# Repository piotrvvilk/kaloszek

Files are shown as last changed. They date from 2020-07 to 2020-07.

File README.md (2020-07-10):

<H1>KALOSZEK - AccuWeather EPD frame</H1> 

<H2> General information</H2>
KALOSZEK is a simple device based on ESP8266 which gets informations shared by AccuWeather and present it on Eink Display. Kaloszek connects to AccuWeather server every 30min. Because AccuWeather trial version allows up to 50 calls per day, device uses 4 separate keys to make sure that the weather will be downloaded 24h a day. After downloading complete information about forcast and current weather, device displays it on screen and go to sleep.
<H2>
</H2>

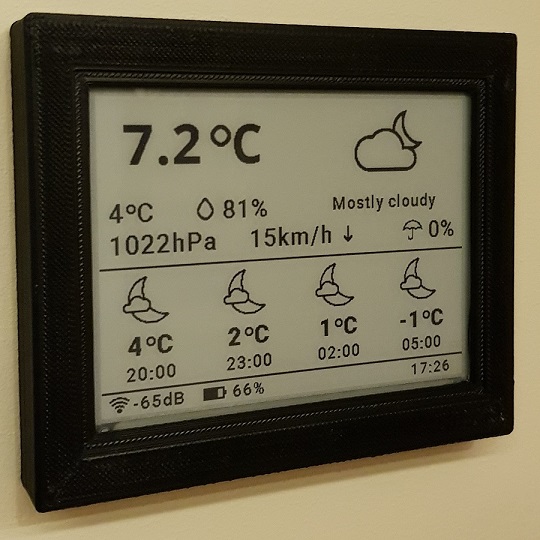
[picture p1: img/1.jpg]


<H2> Hardware </H2>

- Waveshare EPD  4.2inch, 400x300,

- NodeMCU v3,

- Li-ion battery (900mAh),

- Li-ion charger ST4054,

- Li-ion monitor MAX17048,

<H2> Connections </H2>

<H3> </H3>

<H4>EPD : </H4>

- D2 – BUSY

- D3 – CS

- D4 – RST

- D5 – CLK

- D7 – DIN

- D8 – DC (plus external pullup 3k3)

<H3> </H3>

<H4>  MAX17048:</H4>

- D1 – SDA

- D6 – SCL

<H3> </H3>

<H4>Wake up:</H4>

<H3> </H3>

- D0 – RST (remove while programming)

<H2> Libraries</H2>
<H3> </H3>
<H4>  WiFi</H4>
http://www.arduino.cc/en/Reference/WiFi
<H4>  EPD display</H4>
http://github.com/ZinggJM/GxEPD2
<H4>  AccuWeather</H4>
http://github.com/jackmax/AccuWeatherLibrary
<H4>  Json parser</H4>
http://github.com/squix78/json-streaming-parser
<H4>  MAX17048</H4>
http://github.com/hideakitai/MAX17048

<H2> Fonts generator</H2>
http://oleddisplay.squix.ch/#/home

<H2> Icons source</H2>
http://developer.accuweather.com/

<H2> Housing</H2>
<H5>Simple, black :). Designed and printed by Marcin:</H5>
http://www.instagram.com/creatorepic/

<H2> Settings</H2>

You have to edit „authentication.h” file and set your own WiFi SSID, password and accuweather keys. 

<H2> 
</H2>

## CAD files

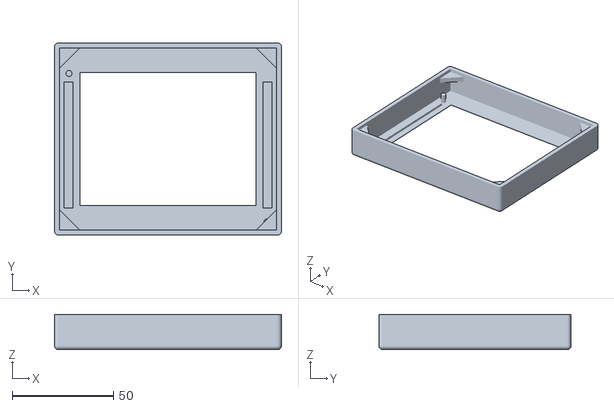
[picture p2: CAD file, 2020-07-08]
housing/kaloszek_housing.stl
112.3 x 95.1 x 17.5

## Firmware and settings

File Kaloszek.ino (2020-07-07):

//*********************************************************
//*****   PROJECT NAME: KALOSZEK                      *****
//*****                                               *****
//*****   VER: 2.6                                    *****
//*****                                               *****
//*****   DATE: 2020-07-07                            *****
//*****                                               *****
//*****                                               *****
//*********************************************************

//*********************************************************
//    LIBRARIES:
//    
//    EPD: https://github.com/ZinggJM/GxEPD2
//    ACCUWEATHER: https://github.com/jackmax/AccuWeatherLibrary
//    JSON ACCU: https://github.com/squix78/json-streaming-parser
//    MAX17048: https://github.com/hideakitai/MAX17048
//
//
//*********************************************************

//*********************************************************
#define ESP8266                     1

#include <ESP8266WiFi.h>
#include <WiFiClient.h>
#include <GxEPD2_BW.h>
#include <JsonListener.h>

#include "AccuWeatherLibrary.h"
#include "authentication.h"
#include "MAX17048.h"

//===========================================================================================================================================
#define     USE_EPD                 1
#define     USE_WIFI                1

#define     USE_ACCUWEATHER         1
#define     USE_HOURLY_FORCAST      1

#define     USE_WIFI_ICO            1

#define     USE_UART                1
//#define     PRINT_WEATHER           1

#define     USE_MAX17048            1

#define     UPDATE_PERIOD           1800                    //seconds
#define     WIFI_ERR_PERIOD         300                     //seconds

//=========================================================================================================================================== 
#include "epd_winddir.h"
#include "epd_iconpack.h"
#include "epd_main_iconpack.h" 
#include "epd_info_iconpack.h"

#include "data/fonts/RobotoMedPlain17.h"
#include "data/fonts/RobotoMedPlain18.h"
#include "data/fonts/RobotoMedPlain25_mod.h"
#include "data/fonts/RobotoBlackPlain25_mod.h"
#include "data/fonts/FreeSansBold52_mod.h"

//===========================================================================================================================================
GxEPD2_BW<GxEPD2_420, GxEPD2_420::HEIGHT> display(GxEPD2_420(/*CS=D3 ss*/ 0 , /*DC=D8*/ 15, /*RST=D4*/ 2, /*BUSY=D2*/ 4));    

const char str_sleep[] = "I'm going to sleep for ";
const char str_seconds[] = "seconds";
const char str_accuweather_err[] = "AccuWeather error";
const char str_wifi_err[] = "Error :(";
const char str_db[] = "dB";
const char str_st1_c[] = "*C";
const char str_uvindex[] = "UV:";
const char str_hpa[] = "hPa";
const char str_percent[] = "% ";
const char str_kmh[] = "km/h";
const char str_bat_error[] = "Battery error";

AccuweatherHourlyData dataH[12];
AccuweatherCurrentData dataC;

int wifi_connection_status;
int weather_status;
int hourly_status;

MAX17048 pwr_mgmt;

const uint16_t pos_x_big_ico = 260;

const int ACU_MAX_KEYS = 4;
int acu_key = 0;

Accuweather aw(acu_keys[0], 274663, "en-en", true);

//===========================================================================================================================================
//===========================================================================================================================================
//===========================================================================================================================================
void setup()
{
//---------------------------------------------------------------------------- SERIAL
#ifdef USE_UART
  Serial.begin(115200);
  Serial.println();
  Serial.println("Setup");
#endif
  delay(100);
  
//---------------------------------------------------------------------------- EPD
#ifdef USE_EPD
  display.init(115200);
#endif

//---------------------------------------------------------------------------- WIFI
#ifdef USE_WIFI
  wifi_connection_status = wifi_connect();
  int timeStart = millis();
#endif

//---------------------------------------------------------------------------- BATTERY
#ifdef USE_MAX17048
  Wire.begin(D1,D6);                          //sda,scl
  pwr_mgmt.attatch(Wire);

  #ifdef USE_UART
    //Serial.print("VCELL ADC : ");
    //Serial.println(pwr_mgmt.adc());
    Serial.print("VCELL V   : ");
    Serial.println(pwr_mgmt.voltage());
    Serial.print("VCELL SOC : ");
    Serial.print(pwr_mgmt.percent());
    Serial.println(" \%");
    //Serial.print("VCELL SOC : ");
    //Serial.print(pwr_mgmt.accuratePercent());
    //Serial.println(" \%");
    Serial.println();
  #endif
 
#endif

//---------------------------------------------------------------------------- ACCUWEATHER
  if (wifi_connection_status == 0)
  {
    do {
      weather_status = get_weather();
      #ifdef USE_UART
        Serial.print("Accu status:");
        Serial.println(weather_status);
      #endif

      hourly_status = get_hourly_forcast();
      #ifdef USE_UART
        Serial.print("Hourly status:");
        Serial.println(hourly_status);
      #endif
      
      if ((weather_status == 0) && (hourly_status == 0)) break;

      acu_key++;
      if (acu_key >= ACU_MAX_KEYS) break;
      Serial.println("Change Accuweather api key");
      aw.changeApiKey(acu_keys[acu_key]);

    } while ((weather_status != 0) || (hourly_status != 0));
  }
  

//---------------------------------------------------------------------------- DISPLAY DATA
#ifdef USE_EPD
  display_weather(wifi_connection_status, weather_status, hourly_status);
#endif

//---------------------------------------------------------------------------- GO TO SLEEP
  if (wifi_connection_status == 0)
  {
    go_to_sleep(UPDATE_PERIOD);
  }
  else
  {
    go_to_sleep(WIFI_ERR_PERIOD);
  }
}
//===========================================================================================================================================
//===========================================================================================================================================
//===========================================================================================================================================
void loop()
{
}

//===========================================================================================================================================
//===========================================================================================================================================
//===========================================================================================================================================
int wifi_connect()
{
//---------------------------------------------------------------------------- WIFI 1
  int i = 50;

  #ifdef USE_UART
    Serial.print("Connecting to: ");
    Serial.println(ssid_1);
  #endif 

  WiFi.mode(WIFI_STA);
  WiFi.begin(ssid_1, password_1);

  do
  {
    if (WiFi.status() == WL_CONNECTED) break;
    delay(500);
    #ifdef USE_UART
      Serial.println("Connecting to WiFi..");
    #endif  
  } while (--i);

  if(i)
  {
    #ifdef USE_UART
      Serial.println("Connected to the WiFi network :)");
      Serial.print("IP address: ");
      Serial.println(WiFi.localIP()); 
    #endif
    return 0;
  }
//---------------------------------------------------------------------------- WIFI 2 (alternative)
    i = 50;
  
    #ifdef USE_UART
      Serial.print("Connecting to: ");
      Serial.println(ssid_2);
    #endif 
  
    WiFi.mode(WIFI_STA);
    WiFi.begin(ssid_2, password_2);
  
    do
    {
      if (WiFi.status() == WL_CONNECTED) break;
      delay(500);
      #ifdef USE_UART
        Serial.println("Connecting to WiFi..");
      #endif  
    } while (--i);
  
    if(i)
    {
      #ifdef USE_UART
        Serial.println("Connected to the WiFi network :)");
        Serial.print("IP address: ");
        Serial.println(WiFi.localIP()); 
      #endif
      return 0;
    }
    else
    {
      #ifdef USE_UART
        Serial.println("WiFi error");
      #endif
        
      return -1;
    }
}

//===========================================================================================================================================
int get_weather()
{
#ifdef USE_ACCUWEATHER
  int timeStart = millis();

  int ret = aw.getCurrent(&dataC);

  if (ret != 0)
  {
    #ifdef USE_UART
      Serial.print("ACCUWEATHER ERROR: ");
      Serial.println(ret);
     #endif

    return ret;
  }

  while (aw.continueDownload() > 0)
  {
  }

  #ifdef PRINT_WEATHER
    print_actual_weather();
  #endif

  timeStart = millis() - timeStart;

  #ifdef USE_UART
    Serial.printf("Downloaded and parsed in %d ms\n", timeStart);
    Serial.println(String(ESP.getFreeHeap()));
  #endif  
  
  return 0;
#else                                                                 //fake data - epd test
  dataC.WeatherText = "Mostly cloudy";
  dataC.WeatherIcon = 7;
  dataC.Temperature = -16.60;
  dataC.RealFeelTemperature = 16.60;
  dataC.RelativeHumidity = 77.00;
  dataC.WindDirection = 115;
  dataC.WindSpeed = 6.70;
  dataC.UVIndex = 1;
  dataC.Pressure = 1023.00;
  return 0;
#endif
}
//===========================================================================================================================================
int get_hourly_forcast()
{
#ifdef USE_HOURLY_FORCAST

  int timeStart = millis();

  int ret = aw.getHourly(&dataH[0], 12);

  if (ret != 0)
  {
    #ifdef USE_UART
      Serial.print("ACCUWEATHER ERROR: ");
      Serial.println(ret);
    #endif
    
    return ret;
  }

  while (aw.continueDownload() > 0)
  {
  }

  //print_dataH();

  timeStart = millis() - timeStart;

  Serial.printf("Downloaded and parsed forcast in %d ms\n", timeStart);
  Serial.println(String(ESP.getFreeHeap()));
#else
  dataH[2].Temperature = -1.20;
  dataH[5].Temperature = 4.40;
  dataH[8].Temperature = 4.90;
  dataH[11].Temperature = 27.90;

  dataH[2].DateTime = "2019-09-21T15:19:21+00:00";
  dataH[5].DateTime = "2019-09-21T18:19:21+00:00";
  dataH[8].DateTime = "2019-09-21T11:19:21+00:00";
  dataH[11].DateTime = "2019-09-22T00:19:21+00:00";

  dataH[1].RainProbability = 13;
#endif

  return 0;
}

//===========================================================================================================================================
void display_weather(int wifi_connection_status, int w_status , int h_status)
{
  char new_date[32];
  char new_data[8];
  float my_temp;

  int pos_y_1_line = 64;    // aktualna temperatura
  int pos_y_2_line = 118;   // temperatura odczuwalna + UV
  int pos_y_w_line = 114;   // opis pogody
  int pos_y_3_line = 148;   // ciśnienie + wilgotność itd
  int pos_y_4_line = 244;   // temp prognozy
  int pos_y_5_line = 268;   // czas prognozy
  int pos_y_6_line = 295;   // status

  int pos_x_wind;
  int pos_x_wind_ico;
  
  int pos_x_prob;
  int pos_x_prob_ico;
  
  display.fillScreen(GxEPD_WHITE);
  display.setRotation(0);
  display.setTextColor(GxEPD_BLACK);
  
//----------------------------------------------------------------------------- background
  display.fillRect(1, 160, 399, 2, GxEPD_BLACK);
  display.fillRect(1, 276, 399, 2, GxEPD_BLACK);
  
//----------------------------------------------------------------------------- 1. line
  if (w_status == 0)
  {
    display.setFont(&Open_Sans_Bold_52);

    my_temp = round(dataC.Temperature * 10) / 10.0;
    display.setCursor(25, pos_y_1_line);
    display.print(my_temp,1);
    display.print(str_st1_c);

//----------------------------------------------------------------------------- 2. line    

//----------------------------------------------------- real_temp
    display.setFont(&Roboto_Medium_25);                                                    
    display.setCursor(10, pos_y_2_line);
   
    int real_temp = (int)(round(dataC.RealFeelTemperature));
    display.print(real_temp);
    display.print(str_st1_c);

//----------------------------------------------------- humidity
    int humidity = int(round(dataC.RelativeHumidity));

    display.drawBitmap(90, pos_y_2_line - 25, hum_ico, 32, 32, GxEPD_BLACK);          //wypozycjonowac
    display.setCursor(122, pos_y_2_line);
    display.print(humidity);
    display.print(str_percent);

//----------------------------------------------------- uv
    //int uv_index = (int)(round(dataC.UVIndex));
    //display.print(str_uvindex);
    //display.print(uv_index);

//----------------------------------------------------------------------------- 3. line

//----------------------------------------------------- pressure     
    int pressure = int(round(dataC.Pressure));
    
    display.setCursor(10, pos_y_3_line);
    display.print(pressure);
    display.print(str_hpa);
    
//----------------------------------------------------- wind 
    int wind_speed = (int)(round(dataC.WindSpeed));   

    if(wind_speed<10)                                                               //ok
    {
      pos_x_wind = 160;
      pos_x_wind_ico = 235;
    }
      else if((wind_speed>9)&&(wind_speed<100))                                     //ok
    {
      pos_x_wind = 150;
      pos_x_wind_ico = 235;
    }
    else                                                                            //ok
    {
      pos_x_wind = 145;
      pos_x_wind_ico = 245;
    }
    
    display.setCursor(pos_x_wind, pos_y_3_line);
    display.print(wind_speed);
    display.print(str_kmh);

    display_wind_dir(dataC.WindDirection, pos_x_wind_ico, pos_y_3_line - 33);       //ok

//----------------------------------------------------- probability
    int prob = (dataH[1].RainProbability);   
  
    if(prob<10)                                                                     //ok
    {
      pos_x_prob_ico = 320;
      pos_x_prob = 357;
    }
      else if((prob>9)&&(prob<100))                                                 //ok
    {
      pos_x_prob_ico = 307;
      pos_x_prob = 345;
    }
    else                                                                            //ok
    {
      pos_x_prob_ico = 295;
      pos_x_prob = 332;
    }

    display.drawBitmap(pos_x_prob_ico, pos_y_3_line - 27, infoIco5, 35, 35, GxEPD_BLACK);     //ok
    display.setCursor(pos_x_prob, pos_y_3_line);
    display.print(prob);
    display.print('%');

//----------------------------------------------------------------------------- main icon and weather description
    display_main_weather_icon(dataC.WeatherIcon, pos_x_big_ico, 4);
    
    uint16_t pos_x_description = set_weather_description_offset(dataC.WeatherText);
    
    display.setFont(&Roboto_Medium_18);                                
    display.setCursor(pos_x_description, pos_y_w_line);
    display.print(dataC.WeatherText);                                                                           

//----------------------------------------------------------------------------- 5. line - update time
    dataC.LocalObservationDateTime.toCharArray(new_date, 20);
    memmove(new_date, new_date + 11, 8);
    memcpy(new_data, new_date, 5);
    new_data[5] = 0;
    display.setCursor(335, pos_y_6_line);
    display.setFont(&Roboto_Medium_17);    
    display.print(new_data);
  }
  else
//----------------------------------------------------------------------------- accuweather error
  {
    display.setFont(&Roboto_Medium_17);    
    display.setCursor(232, pos_y_6_line);
    display.print(str_accuweather_err);
  }
  
//----------------------------------------------------------------------------- wifi
  display.setFont(&Roboto_Medium_17);   
  display.setCursor(30, pos_y_6_line);

#ifdef USE_WIFI_ICO
  display.drawBitmap(6, 281, wifi_ico, 24, 16, GxEPD_BLACK); 
#endif

  if (wifi_connection_status == 0)
  {
     #ifndef USE_WIFI_ICO
      display.print(WiFi.SSID());
      display.print(' ');
    #endif  
    
    display.print(WiFi.RSSI());
    
    display.print(str_db);
  }
  else
  {
    display.print(str_wifi_err);
  }

//----------------------------------------------------------------------------- battery
  display_battery(pos_y_6_line); 

//----------------------------------------------------------------------------- weather forcast
  if (h_status == 0) 
  {
    display_forcast(2, pos_y_4_line, pos_y_5_line);         //3h
    display_forcast(5, pos_y_4_line, pos_y_5_line);         //6h
    display_forcast(8, pos_y_4_line, pos_y_5_line);         //9h
    display_forcast(11, pos_y_4_line, pos_y_5_line);        //12h
  }

  display.display();
  display.powerOff();
  display.hibernate();
  Serial.println("EPD is sleeping");
}

//===========================================================================================================================================
void display_forcast(int idx, int pos_y_temp, int pos_y_time)
{
  float my_temp = round(dataH[idx].Temperature * 10) / 10.0;
  char new_date[32];
  char new_data[8];
  int pos_x_ico;
  int pos_x_time;
  int pos_x_temp;

//-------------------------------------------------- temp & ico
  int my_t = (int)(round(my_temp));  

  switch(idx)
  {
    case 2: pos_x_ico = 22; pos_x_time = pos_x_ico + 2; pos_x_temp = set_forcast_temperature_position(pos_x_ico, my_t); break;
    case 5: pos_x_ico = 122; pos_x_time = pos_x_ico + 2; pos_x_temp = set_forcast_temperature_position(pos_x_ico, my_t);  break;        
    case 8: pos_x_ico = 222; pos_x_time = pos_x_ico + 2; pos_x_temp = set_forcast_temperature_position(pos_x_ico, my_t); break;        
    case 11: pos_x_ico = 322; pos_x_time = pos_x_ico + 2; pos_x_temp = set_forcast_temperature_position(pos_x_ico, my_t); break;
  }
  
  display_hourly_weather_icon(dataH[idx].WeatherIcon, pos_x_ico, pos_y_temp - 80);

  display.setFont(&Roboto_Black_25); 
  display.setCursor(pos_x_temp, pos_y_temp);
  display.print(my_t);
  display.print(str_st1_c);

//-------------------------------------------------- time
  dataH[idx].DateTime.toCharArray(new_date, 20);
  memmove(new_date, new_date + 11, 8);
  memcpy(new_data, new_date, 5);
  new_data[5] = 0;

  display.setFont(&Roboto_Medium_18);                                            
  display.setCursor(pos_x_time, pos_y_time);
  display.print(new_data);
}

//===========================================================================================================================================
uint16_t set_weather_description_offset(String str)
{
  int16_t tbx, tby; 
  uint16_t tbw, tbh;

  display.setFont(&Roboto_Medium_18);                                
  display.getTextBounds(str.c_str(), 0, 0, &tbx, &tby, &tbw, &tbh);

  uint16_t x_center = pos_x_big_ico + (90/2);               //srodek ikonki pogody 90 - uwzglednic wielkosc ikonki w obliczeniach
  uint16_t  pos_x_napisu = (x_center - (tbw / 2)) - tbx;
 
  return pos_x_napisu;
}

//===========================================================================================================================================
int set_forcast_temperature_position(int pos_x, int temp)
{
  if(temp<-9)                               
  {
    return pos_x-8;
  }
  else if((temp>-10)&&(temp<0))             
  {
    return pos_x-2;
  }
  else if((temp>-1)&&(temp<10))            
  {
     return pos_x+4;
  }
  else                                    
  {
    return pos_x-2;
  }
}

//===========================================================================================================================================
void set_icon_offset(uint8_t w_number, int *x_pos, int *y_pos) {
#ifdef ICON_PACK_3
  switch (w_number)
  {
    case 3: {
        *y_pos += 2;
      } break;
    case 38: {
        *y_pos += 8;
      } break;
  }
#endif
}
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

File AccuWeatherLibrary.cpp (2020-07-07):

#include "AccuWeatherLibrary.h"
#include "JsonListener.h"

#define SIZE_OF_CONST_TABLE(x) sizeof(x)/sizeof(x[0])
#define STACK_HAS_SUFFIX(x) stackSuffix(x, SIZE_OF_CONST_TABLE(x))
/*
 *  Parser constants
 */
//A map to transform strings into tokens
static const std::map<const String, const AccuParserTokens> stringToTokenMap = {
    { "CloudCover", ACCUPARSERCloudCover },
    { "DailyForecasts", ACCUPARSERDailyForecasts },
    { "Date", ACCUPARSERDate },
    { "DateTime", ACCUPARSERDateTime },
    { "Day", ACCUPARSERDay },
    { "Degrees", ACCUPARSERDegrees },
    { "Direction", ACCUPARSERDirection },
    { "English", ACCUPARSEREnglish },
    { "EpochDate", ACCUPARSEREpochDate },
    { "EpochDateTime", ACCUPARSEREpochDateTime },
    { "EpochRise", ACCUPARSEREpochRise },
    { "EpochSet", ACCUPARSEREpochSet },
    { "EpochTime", ACCUPARSEREpochTime },
    { "HoursOfSun", ACCUPARSERHoursOfSun },
    { "Ice", ACCUPARSERIce },
    { "IceProbability", ACCUPARSERIceProbability },
    { "Icon", ACCUPARSERIcon },
    { "IconPhrase", ACCUPARSERIconPhrase },
    { "Imperial", ACCUPARSERImperial },
    { "IsDaylight", ACCUPARSERIsDaylight },
    { "IsDayTime", ACCUPARSERIsDayTime },
    { "LocalObservationDateTime", ACCUPARSERLocalObservationDateTime },
    { "LongPhrase", ACCUPARSERLongPhrase },
    { "Maximum", ACCUPARSERMaximum },
    { "Metric", ACCUPARSERMetric },
    { "Minimum", ACCUPARSERMinimum },
    { "Moon", ACCUPARSERMoon },
    { "Night", ACCUPARSERNight },
    { "Precip1hr", ACCUPARSERPrecip1hr },
    { "PrecipitationProbability", ACCUPARSERPrecipitationProbability },
    { "Pressure", ACCUPARSERPressure },
    { "Rain", ACCUPARSERRain },
    { "RainProbability", ACCUPARSERRainProbability },
    { "RealFeelTemperature", ACCUPARSERRealFeelTemperature },
    { "RealFeelTemperatureShade", ACCUPARSERRealFeelTemperatureShade },
    { "RelativeHumidity", ACCUPARSERRelativeHumidity },
    { "ShortPhrase", ACCUPARSERShortPhrase },
    { "Snow", ACCUPARSERSnow },
    { "SnowProbability", ACCUPARSERSnowProbability },
    { "Speed", ACCUPARSERSpeed },
    { "Sun", ACCUPARSERSun },
    { "Temperature", ACCUPARSERTemperature },
    { "ThunderstormProbability", ACCUPARSERThunderstormProbability },
    { "TotalLiquid", ACCUPARSERTotalLiquid },
    { "Unit", ACCUPARSERUnit },
    { "UVIndex", ACCUPARSERUVIndex },
    { "UVIndexText", ACCUPARSERUVIndexText },
    { "Value", ACCUPARSERValue },
    { "Visibility", ACCUPARSERVisibility },
    { "WeatherIcon", ACCUPARSERWeatherIcon },
    { "WeatherText", ACCUPARSERWeatherText },
    { "Wind", ACCUPARSERWind },
    { "WindGust", ACCUPARSERWindGust },
};

//Arrays of stack suffixes - if the stack has this suffix, this means that this piece of data can be obtained
static const AccuParserTokens LocalObservationDateTime_suffix[] = {ACCUPARSERLocalObservationDateTime};
static const AccuParserTokens DateTime_suffix[] = {ACCUPARSERDateTime};
static const AccuParserTokens EpochTime_suffix[] = {ACCUPARSEREpochTime};
static const AccuParserTokens EpochDateTime_suffix[] = {ACCUPARSEREpochDateTime};
static const AccuParserTokens Date_suffix[] = {ACCUPARSERDate};
static const AccuParserTokens EpochDate_suffix[] = {ACCUPARSEREpochDate};
static const AccuParserTokens HoursOfSun_suffix[] = {ACCUPARSERHoursOfSun};
static const AccuParserTokens WeatherText_suffix[] = {ACCUPARSERWeatherText};
static const AccuParserTokens WeatherIcon_suffix[] = {ACCUPARSERWeatherIcon};
static const AccuParserTokens Icon_suffix[] = {ACCUPARSERIcon};
static const AccuParserTokens IconPhrase_suffix[] = {ACCUPARSERIconPhrase};
static const AccuParserTokens LongPhrase_suffix[] = {ACCUPARSERLongPhrase};
static const AccuParserTokens IsDayTime_suffix[] = {ACCUPARSEREpochTime};
static const AccuParserTokens IsDaylight_suffix[] = {ACCUPARSERIsDaylight};
static const AccuParserTokens RelativeHumidity_suffix[] = {ACCUPARSERRelativeHumidity};
static const AccuParserTokens WindDirection_suffix[] = {ACCUPARSERWind, ACCUPARSERObject, ACCUPARSERDirection, ACCUPARSERObject, ACCUPARSERDegrees};
static const AccuParserTokens UVIndex_suffix[] = {ACCUPARSERUVIndex};
static const AccuParserTokens UVIndexText_suffix[] = {ACCUPARSERUVIndexText};
static const AccuParserTokens CloudCover_suffix[] = {ACCUPARSERCloudCover};

static const AccuParserTokens UnitTemperature_suffix[] = {ACCUPARSERTemperature, ACCUPARSERObject, ACCUPARSERUnitPlaceholder, ACCUPARSERObject, ACCUPARSERValue};
static const AccuParserTokens RealFeelUnitTemperature_suffix[] = {ACCUPARSERRealFeelTemperature, ACCUPARSERObject, ACCUPARSERUnitPlaceholder, ACCUPARSERObject, ACCUPARSERValue};
static const AccuParserTokens RealFeelUnitTemperatureShade_suffix[] = {ACCUPARSERRealFeelTemperatureShade, ACCUPARSERObject, ACCUPARSERUnitPlaceholder, ACCUPARSERObject, ACCUPARSERValue};
static const AccuParserTokens WindUnitSpeed_suffix[] = {ACCUPARSERWind, ACCUPARSERObject, ACCUPARSERSpeed, ACCUPARSERObject, ACCUPARSERUnitPlaceholder, ACCUPARSERObject, ACCUPARSERValue};
static const AccuParserTokens WindGustUnitSpeed_suffix[] = {ACCUPARSERWindGust, ACCUPARSERObject, ACCUPARSERSpeed, ACCUPARSERObject, ACCUPARSERUnitPlaceholder, ACCUPARSERObject, ACCUPARSERValue};
static const AccuParserTokens UnitPressure_suffix[] = {ACCUPARSERPressure, ACCUPARSERObject, ACCUPARSERUnitPlaceholder, ACCUPARSERObject, ACCUPARSERValue};
static const AccuParserTokens UnitVisibility_suffix[] = {ACCUPARSERVisibility, ACCUPARSERObject, ACCUPARSERUnitPlaceholder, ACCUPARSERObject, ACCUPARSERValue};

static const AccuParserTokens Temperature_suffix[] = {ACCUPARSERTemperature, ACCUPARSERObject, ACCUPARSERValue};
static const AccuParserTokens RealFeelTemperature_suffix[] = {ACCUPARSERRealFeelTemperature, ACCUPARSERObject, ACCUPARSERValue};
static const AccuParserTokens RealFeelTemperatureShade_suffix[] = {ACCUPARSERRealFeelTemperatureShade, ACCUPARSERObject, ACCUPARSERValue};
static const AccuParserTokens WindSpeed_suffix[] = {ACCUPARSERWind, ACCUPARSERObject, ACCUPARSERSpeed, ACCUPARSERObject, ACCUPARSERValue};
static const AccuParserTokens WindGustSpeed_suffix[] = {ACCUPARSERWindGust, ACCUPARSERObject, ACCUPARSERSpeed, ACCUPARSERObject, ACCUPARSERValue};
static const AccuParserTokens Pressure_suffix[] = {ACCUPARSERPressure, ACCUPARSERObject, ACCUPARSERValue};
static const AccuParserTokens Visibility_suffix[] = {ACCUPARSERVisibility, ACCUPARSERObject, ACCUPARSERValue};
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
